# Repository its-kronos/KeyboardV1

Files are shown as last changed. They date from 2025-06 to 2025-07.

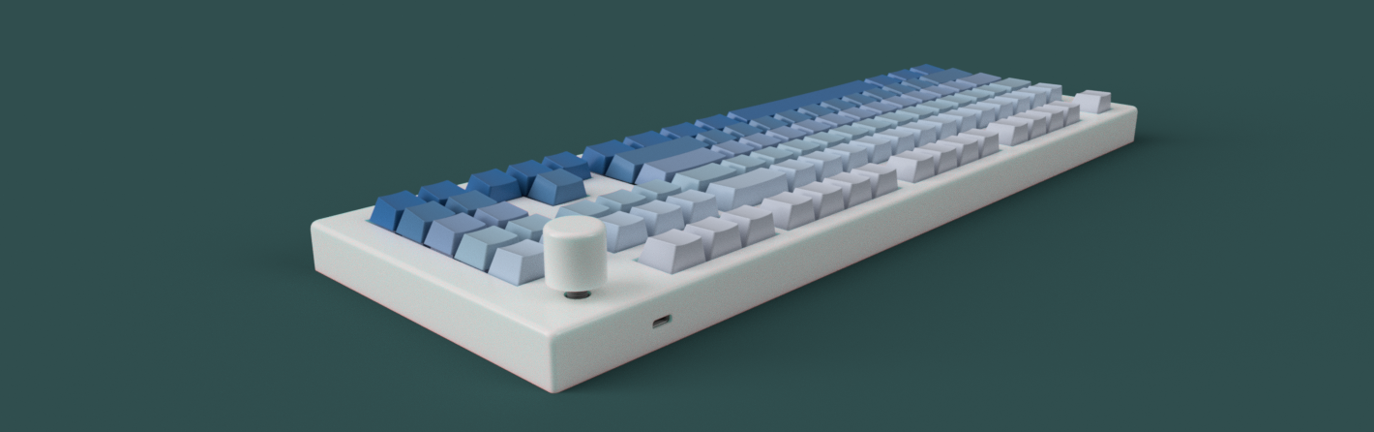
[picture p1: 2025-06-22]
Assets/Assembly.png

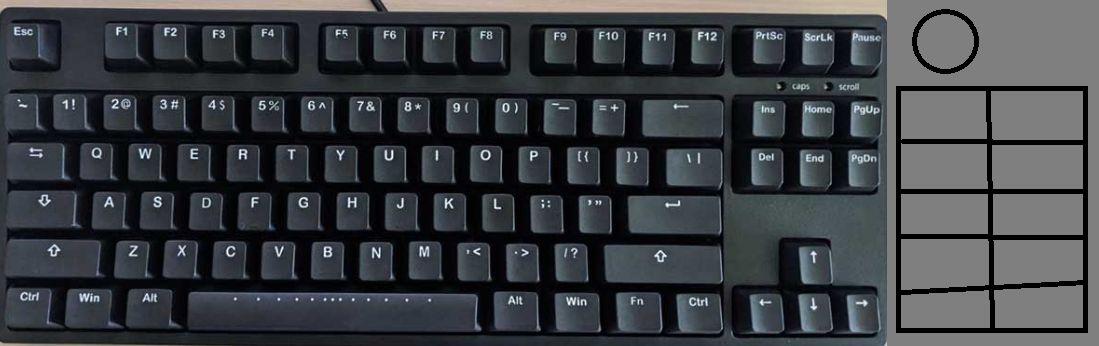
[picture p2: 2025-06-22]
Assets/LayoutPNG/Layout.png

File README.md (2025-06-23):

# MacroBoard

Assembly

# What is it?  
  
- The MacroBoard is an extension of a much smaller "macropad" featuring a **full TKL layout** with a **rotary encoder** for volume and a whopping total of **22 macro keys** (10 macrokeys physically and 12 more due to the fn keys being on another layer), and it is all coded with KMK firmware.
- Worried about the amount of power it will take? No need to worry! The MacroBoard has a **Pi Pico** as its brain, which is pretty efficient on energy.
- Dislike the microUSB connector on the Pi Pico? Again, don't worry! Through the use of a **USB Type-C** breakout board, most of the cables that you already use should work, as the keyboard has the necessary 5.1K ohm resistors to allow for type-C to type-C communication
- Case looking too big? Every model is split in half to allow for printing on a consumer-sized printer.

# Why did I make it?  
  
- One of my first hardware projects in my life was a macropad, and since I didn't have that much experience, I thought that a keyboard would be an appropriate step up in difficulty while still challenging myself, especially because I decided to use a **bare rp2040 chip** and had to include everything that it needs, including differential pair routing with 90 ohm impedence (for the USB-C connection).
- For the form-factor, I decided to add macrokeys as having additional components like a macroboard on my desk would feel like clutter, so incorporating these keys into the keyboard itself would fix this issue
- Finally, I just never used a mechanical keyboard before, and I honestly just wanted to know how it felt compared to the laptop keyboards and the ones based on rubber.



# Challenges  
  
- There were two points in this project that were quite soul-crushing and made me actually consider if I should just stop trying to complete the project, which is why I want to highlight them here.

- Initially, I decided that I would forgo hotswap switches for the keyboard, but after finishing routing the PCB, I chose that it would probably be better if I decided to include them. When I changed the footprints from Cherry MX to Kailh hotswap switches, there were over 1300 errors in the DRC.
- This meant that I would have to completely restart the wiring, which was pretty difficult for me to accept, but luckily, it took around 25% of the time it took before with my gained knowledge, proving to me how far I have come in this month alone.



- The next challenge happened right at the end of my project, or as I was almost ready to be done. When I uploaded the PCB gerber files to JLCPCB and completed the parts selection, I found out that no matter what I did, the bare board would come out to be over 1.5 KG, making it ineligible for Global Direct Shipping.
- This meant that the shipping for just the PCB would come out to be about 40 dollars with the cheapest option, completely breaking the $150 budget I had for this project.
- I asked around on the Hackclub Slack for some help, and I there seemed to be nothing that I could really do.
- As a last resort, I DMed [Ayo](https://github.com/TheEternalComrade) (you should check out his Github), who I had seen complete a keyboard. After discussing about ways to optimize the price, he brought up the idea of hand-wiring a keyboard, which was something I had never thought of before.
- I initially still felt discouraged, but with more conversation, I slowly became more confident in myself and my abilities. Now, rejuvinated, I updated the models to be able to work without a PCB and quickly finished my project



# Credits
- Credit to [@Coloneljesus_13723 on printables.com](https://www.printables.com/model/680438-switch-to-encoder-plate-adapter/files) for a cherry MX plate hole to EC11 rotary encoder
- [Ayo](https://github.com/TheEternalComrade) for helping me throughout the latter part of the project

# PCB

- As previously stated, I will be handwiring this keyboard, but here is my wiring diagram for the keyboard and the PCB that I did design (which ended up being too expensive)





# CAD
- This took me a pretty long time since I'm relatively new to designing things, but I feel that it turned out really well.



# BOM

|VENDER |ITEM |PRICE (USD) |SHIPPING|PCS |COUNT|COMMENT |COMMENT |
|---|---|---|---|---|-----|---|---|
| | | | | | | | |
|ALIEXPRESS| | | | | | | |
| |[FEET](https://www.aliexpress.us/item/3256807883232459.html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) |1.69 |0 |10 |1 | | |
| |[KEYCAPS](https://www.aliexpress.us/item/3256808583283524.html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) |20.22 |0 |104 |1 |BLUE | |
| |[STABS](https://www.aliexpress.us/item/3256806342416791.html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) |7.69 |0 |(1) 6.25u, (4) 2u|1 | | |
| |[ROTARY](https://www.aliexpress.us/item/3256806989461658.html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) |1.42 |0 |1 |0 |EXCLUDED | |
| |[HEADERS](https://www.aliexpress.us/item/3256804251926023.html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) |1.44 |1.99 |10 |0 |EXCLUDED | |
| |[STANDOFFS](https://www.aliexpress.us/item/3256807676471039.html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) |3.08 |0 |100 |1 |6mm M3 | |
| |[SCREWS](https://www.aliexpress.us/item/3256808318392916.html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) |2.12 |0 |50 |1 |14mm M3 | |
| |SCREWS (same as above) |1.81 |0 |50 |1 |8mm M3 | |
| |[WIRE](https://www.aliexpress.us/item/3256807263561521.html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) |5.04 |0 |10m |2 |22 AWG |PRICE IS FOR BOTH|
| |[SOLDER](https://www.aliexpress.us/item/2251832799951126.html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) |5.36 |0 |50G |1 |LEAD-FREE | |
| |[BRASS SPONGE](https://www.aliexpress.us/item/3256807379310777.html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,scm-url:1007.40050.354490.0,pvid:908ff35d-5b9a-412a-95bf-02d25e162938,tpp_buckets:668%232846%238107%231934&pdp_ext_f=%7B%22order%22%3A%2212272%22%2C%22eval%22%3A%221%22%2C%22sceneId%22%3A%2230050%22%7D&pdp_npi=4%40dis%21USD%211.23%211.02%21%21%211.23%211.02%21%40210308a417506046727721251ec22e%2112000041321995436%21rec%21US%21%21ABXZ&utparam-url=scene%3ApcDetailTopMoreOtherSeller%7Cquery_from%3A#nav-specification) |3.67 |0 |1 |1 |(so hackclub doesn't have to pay for tips in the future)| |
| |[DIODES](https://www.aliexpress.us/item/2255799955957794.html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) |1.46 |0 |100 |1 | | |
| | | | | | | | |
| |TOTAL |52.14 | | | | | |
| | | | | | | | |
|AMAZON | | | | | | | |
| |[GLUE](https://www.amazon.com/Gorilla-Precise-Cyanoacrylate-Dispensing-Anti-Clog/dp/B0CTHY7QTY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) |7.49 |0 |1 |1 | | |
| |[PICO](https://www.amazon.com/Raspberry-RP2040-microcontroller-Dual-core-Processor-1pc/dp/B0BK9CTMSV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) |7.48 |0 |2 |1 | | |
| |[USBC BREAKOUT](https://www.amazon.com/DIANN-Type-C-Breakout-Connector-Converter/dp/B0BLSN5PR8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)|5.99 |0 |5 |1 | | |
| |[WIRE STRIPPER](https://www.amazon.com/WGGE-Professional-crimping-Multi-Tool-Multi-Function/dp/B073YG65N2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)|8.99 |0 |1 |1 | | |
| |[SWITCHES](https://www.amazon.com/Switches-Mechanical-Keyboard-Pre-Lubed-Pin-Enhanced/dp/B0CF8CVWV8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) |32.99 |0 |108 |1 |gateron yellow | |
| | | | | | | | |
| |TOTAL |62.94 | | | | | |
| | | | | | | | |
|SHIPPING  |20 |(reserved for printing legion shipping) | | | | | |
|TAXES | |(Have more than enough for my state sales tax)| | | | | |
| | | | | | | | |
|TOTAL |135.08 | | | | | | |

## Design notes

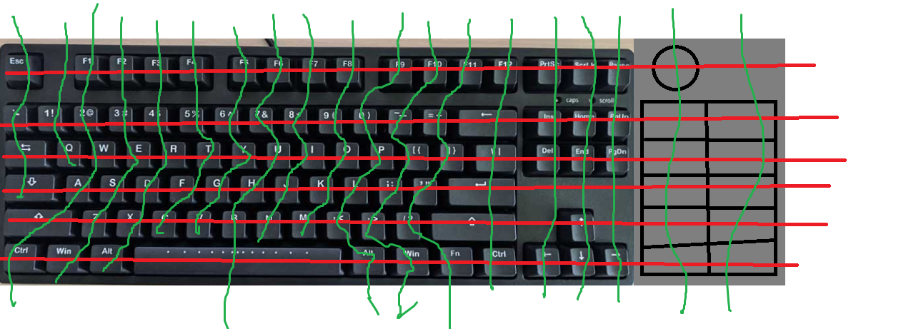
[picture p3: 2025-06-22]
Assets/LayoutPNG/Matrix.png

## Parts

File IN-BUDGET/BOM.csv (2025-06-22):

VENDER | ITEM | PRICE | SHIPPING | PCS | COUNT | COMMENT | COMMENT
ALIEXPRESS
 | FEET | 1.69 | 0 | 10 | 1
 | KEYCAPS | 20.22 | 0 | 104 | 1 | BLUE
 | STABS | 7.69 | 0 | (1) 6.25u, (4) 2u | 1
 | ROTARY | 1.42 | 0 | 1 | 0 | EXCLUDED
 | HEADERS | 1.44 | 1.99 | 10 | 0 | EXCLUDED
 | STANDOFFS | 3.08 | 0 | 100 | 1 | 6mm M3
 | SCREWS | 2.12 | 0 | 50 | 1 | 14mm M3
 | SCREWS | 1.81 | 0 | 50 | 1 | 8mm M3
 | WIRE | 5.04 | 0 | 10m | 2 | 22 AWG | PRICE IS FOR BOTH
 | SOLDER | 5.36 | 0 | 50G | 1 | LEAD-FREE
 | BRASS SPONGE | 3.67 | 0 | 1 | 1 | (so hackclub doesn’t have to pay for tips in the future)
 | DIODES | 1.46 | 0 | 100 | 1
 | TOTAL | 52.14
AMAZON
 | GLUE | 7.49 | 0 | 1 | 1
 | PICO | 7.48 | 0 | 2 | 1
 | USBC BREAKOUT | 5.99 | 0 | 5 | 1
 | WIRE STRIPPER | 8.99 | 0 | 1 | 1
 | SWITCHES | 32.99 | 0 | 108 | 1 | gateron yellow
 | TOTAL | 62.94
SHIPPING | 20 | (reserved for printing legion shipping)
TAXES |  | (Have more than enough for my state sales tax)
TOTAL | 135.08

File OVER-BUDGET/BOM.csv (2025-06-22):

JLC
 | PCB | 27.2
 | PCBA | 38.8 | (probably since I’m using RP2040 bare, meaning a lot of extended components)
 | PLATE | 6.83
 | shipping | 36.96
 | JLC TOTAL | 109.79
ALIEXPRESS
 | [switches](https://www.aliexpress.us/item/3256802556025161.html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) | 47.67 |  |  | cherry silver | 104 count
 | [keycaps]https://www.aliexpress.us/item/3256808583283524.html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 | 20.22 |  |  | gradient blue | 100% keyboard set
 | [STABS](https://www.aliexpress.us/item/3256806342416791.html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) | 7.69 |  |  |  | 4 2U 1 6.25U
 | [ENCODER](https://www.aliexpress.us/item/3256806989461658.html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 | 1.42 |  |  | ec11
 | [PIN_HEADERS](https://www.aliexpress.us/item/3256804251926023.html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) | 1.44 | 1.99 | (1.99 is shipping) | Uses 1x2 | 10 PCS
 | [STANDOFFS](https://www.aliexpress.us/item/3256807676471039.html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) | 3.94 |  |  | 6mm | 100 PCS
 | [SCREWS](https://www.aliexpress.us/item/3256808318392916.html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) | 1.58 |  |  | M3 6mm | 50 PCS
 | [SCREWS](https://www.aliexpress.us/item/3256808318392916.html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) | 2.03 |  |  | M3 12mm | 50 PCS
 | TOTAL | 87.98
AMAZON
 | [HOTSWAP](https://www.amazon.com/DUROCK-Mechanical-Keyboard-Switches-Hot-Swap/dp/B0B4W9YMGM | 13.99 |  |  |  | 110 PCS
 | [SUPERGLUE](https://www.amazon.com/Gorilla-Precise-Cyanoacrylate-Dispensing-Anti-Clog/dp/B0CTHY7QTY?s=office-products | 7.49
 | TOTAL | 21.48
SHIPPING (for Printing Legion)
 | SHIPPING | 20 | (at most, just an estimate)
 | TOTAL | 20
TOTAL PRICE | 239.25

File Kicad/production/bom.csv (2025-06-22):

Designator | Footprint | Quantity | Value | LCSC Part #
C1, C2 | 1206 | 2 | C10u
C10, C11 | 0402 | 2 | C15p
C12, C13, C14, C15, C16, C17, C4, C6, C7, C8, C9 | 0402 | 11 | C100n
C3, C5 | 0402 | 2 | C1u
D1 | D_SOD-323 | 1 | Esc
D10 | D_SOD-323 | 1 | F9
D11 | D_SOD-323 | 1 | F10
D12 | D_SOD-323 | 1 | F11
D13 | D_SOD-323 | 1 | F12
D14 | D_SOD-323 | 1 | PrtScrn
D15 | D_SOD-323 | 1 | Screen Lock
D16 | D_SOD-323 | 1 | Pause
D17 | D_SOD-323 | 1 | D
D18 | D_SOD-323 | 1 | KEY`
D19 | D_SOD-323 | 1 | KEY1
D2 | D_SOD-323 | 1 | F1
D20 | D_SOD-323 | 1 | KEY2
D21 | D_SOD-323 | 1 | KEY3
D22 | D_SOD-323 | 1 | KEY4
D23 | D_SOD-323 | 1 | KEY5
D24 | D_SOD-323 | 1 | KEY6
D25 | D_SOD-323 | 1 | KEY7
D26 | D_SOD-323 | 1 | KEY8
D27 | D_SOD-323 | 1 | KEY9
D28 | D_SOD-323 | 1 | KEY0
D29 | D_SOD-323 | 1 | KEY-
D3 | D_SOD-323 | 1 | F2
D30 | D_SOD-323 | 1 | KEY=
D31 | D_SOD-323 | 1 | BKSP
D32 | D_SOD-323 | 1 | Ins
D33 | D_SOD-323 | 1 | Home
D34 | D_SOD-323 | 1 | PgUP
D35 | D_SOD-323 | 1 | M1
D36 | D_SOD-323 | 1 | M2
D37 | D_SOD-323 | 1 | TAB
D38 | D_SOD-323 | 1 | KEYQ
D39 | D_SOD-323 | 1 | KEYW
D4 | D_SOD-323 | 1 | F3
D40 | D_SOD-323 | 1 | KEYE
D41 | D_SOD-323 | 1 | KEYR
D42 | D_SOD-323 | 1 | KEYT
D43 | D_SOD-323 | 1 | KEYY
D44 | D_SOD-323 | 1 | KEYU
D45 | D_SOD-323 | 1 | KEYI
D46 | D_SOD-323 | 1 | KEYO
D47 | D_SOD-323 | 1 | KEYP
D48 | D_SOD-323 | 1 | KEY[
D49 | D_SOD-323 | 1 | KEY]
D5 | D_SOD-323 | 1 | F4
D50 | D_SOD-323 | 1 | KEY\
D51 | D_SOD-323 | 1 | Del
D52 | D_SOD-323 | 1 | End
D53 | D_SOD-323 | 1 | PgDN
D54 | D_SOD-323 | 1 | M3
D55 | D_SOD-323 | 1 | M4
D56 | D_SOD-323 | 1 | CAPS
D57 | D_SOD-323 | 1 | KEYA
D58 | D_SOD-323 | 1 | KEYS
D59 | D_SOD-323 | 1 | KEYD
D6 | D_SOD-323 | 1 | F5
D60 | D_SOD-323 | 1 | KEYF
D61 | D_SOD-323 | 1 | KEYG
D62 | D_SOD-323 | 1 | KEYH
D63 | D_SOD-323 | 1 | KEYJ
D64 | D_SOD-323 | 1 | KEYK
D65 | D_SOD-323 | 1 | KEYL
D66 | D_SOD-323 | 1 | KEY;
D67 | D_SOD-323 | 1 | KEY"
D68 | D_SOD-323 | 1 | ENTER
D69 | D_SOD-323 | 1 | M5
D7 | D_SOD-323 | 1 | F6
D70 | D_SOD-323 | 1 | M6
D71 | D_SOD-323 | 1 | LSHIFT
D72 | D_SOD-323 | 1 | KEYZ
D73 | D_SOD-323 | 1 | KEYX
D74 | D_SOD-323 | 1 | KEYC
D75 | D_SOD-323 | 1 | KEYV
D76 | D_SOD-323 | 1 | KEYB
D77 | D_SOD-323 | 1 | KEYN
D78 | D_SOD-323 | 1 | KEYM
D79 | D_SOD-323 | 1 | KEY,
D8 | D_SOD-323 | 1 | F7
D80 | D_SOD-323 | 1 | KEY.
D81 | D_SOD-323 | 1 | KEY/
D82 | D_SOD-323 | 1 | RSHIFT
D83 | D_SOD-323 | 1 | Up Arrow
D84 | D_SOD-323 | 1 | M7
D85 | D_SOD-323 | 1 | M8
D86 | D_SOD-323 | 1 | LCTRL
D87 | D_SOD-323 | 1 | LWIN
D88 | D_SOD-323 | 1 | LALT
D89 | D_SOD-323 | 1 | SPACE
D9 | D_SOD-323 | 1 | F8
D90 | D_SOD-323 | 1 | RALT
D91 | D_SOD-323 | 1 | RWIN
D92 | D_SOD-323 | 1 | FN
D93 | D_SOD-323 | 1 | RCTRL
D94 | D_SOD-323 | 1 | Left Arrow
D95 | D_SOD-323 | 1 | Down Arrow
D96 | D_SOD-323 | 1 | Right Arrow
D97 | D_SOD-323 | 1 | M9
D98 | D_SOD-323 | 1 | M10
J2 | PinHeader_1x02_P2.54mm_Vertical | 1 | Conn_01x02
J3 | Korean Hroparts Elec - Type C 31 M 12 - 16P - USB 2.0 | 1 | USBC
R1, R2 | 0603 | 2 | R5.1k
R3, R5 | 0402 | 2 | R1K
R4, R8 | 0402 | 2 | R10K
R6, R7 | 0402 | 2 | R27.4
SW1 | RotaryEncoder_Alps_EC11E-Switch_Vertical_H20mm_MountingHoles | 1 | RotaryEncoder_Switch
SW10 | SW_Hotswap_Kailh_MX_Plated_1.00u | 1 | F8
SW11 | SW_Hotswap_Kailh_MX_Plated_1.00u | 1 | F9
SW12 | SW_Hotswap_Kailh_MX_Plated_1.00u | 1 | F10
SW13 | SW_Hotswap_Kailh_MX_Plated_1.00u | 1 | F11
SW14 | SW_Hotswap_Kailh_MX_Plated_1.00u | 1 | F12
SW15 | SW_Hotswap_Kailh_MX_Plated_1.00u | 1 | PrtScrn
SW16 | SW_Hotswap_Kailh_MX_Plated_1.00u | 1 | Screen Lock
SW17 | SW_Hotswap_Kailh_MX_Plated_1.00u | 1 | Pause
SW18 | SW_Hotswap_Kailh_MX_Plated_1.00u | 1 | KEY`
SW19 | SW_Hotswap_Kailh_MX_Plated_1.00u | 1 | KEY1
SW2 | SW_Hotswap_Kailh_MX_Plated_1.00u | 1 | Esc
SW20 | SW_Hotswap_Kailh_MX_Plated_1.00u | 1 | KEY2
SW21 | SW_Hotswap_Kailh_MX_Plated_1.00u | 1 | KEY3
SW22 | SW_Hotswap_Kailh_MX_Plated_1.00u | 1 | KEY4
SW23 | SW_Hotswap_Kailh_MX_Plated_1.00u | 1 | KEY5
SW24 | SW_Hotswap_Kailh_MX_Plated_1.00u | 1 | KEY6
SW25 | SW_Hotswap_Kailh_MX_Plated_1.00u | 1 | KEY7
SW26 | SW_Hotswap_Kailh_MX_Plated_1.00u | 1 | KEY8
SW27 | SW_Hotswap_Kailh_MX_Plated_1.00u | 1 | KEY9
SW28 | SW_Hotswap_Kailh_MX_Plated_1.00u | 1 | KEY0
SW29 | SW_Hotswap_Kailh_MX_Plated_1.00u | 1 | KEY-
SW3 | SW_Hotswap_Kailh_MX_Plated_1.00u | 1 | F1
SW30 | SW_Hotswap_Kailh_MX_Plated_1.00u | 1 | KEY=
SW31 | SW_Hotswap_Kailh_MX_Plated_2.00u | 1 | BKSP
SW32 | SW_Hotswap_Kailh_MX_Plated_1.00u | 1 | Ins
SW33 | SW_Hotswap_Kailh_MX_Plated_1.00u | 1 | Home
SW34 | SW_Hotswap_Kailh_MX_Plated_1.00u | 1 | PgUP
SW35 | SW_Hotswap_Kailh_MX_Plated_1.00u | 1 | M1
SW36 | SW_Hotswap_Kailh_MX_Plated_1.00u | 1 | M2
SW37 | SW_Hotswap_Kailh_MX_Plated_1.50u | 1 | TAB
SW38 | SW_Hotswap_Kailh_MX_Plated_1.00u | 1 | KEYQ
SW39 | SW_Hotswap_Kailh_MX_Plated_1.00u | 1 | KEYW
SW4 | SW_Hotswap_Kailh_MX_Plated_1.00u | 1 | F2
SW40 | SW_Hotswap_Kailh_MX_Plated_1.00u | 1 | KEYE
SW41 | SW_Hotswap_Kailh_MX_Plated_1.00u | 1 | KEYR
SW42 | SW_Hotswap_Kailh_MX_Plated_1.00u | 1 | KEYT
SW43 | SW_Hotswap_Kailh_MX_Plated_1.00u | 1 | KEYY
SW44 | SW_Hotswap_Kailh_MX_Plated_1.00u | 1 | KEYU
SW45 | SW_Hotswap_Kailh_MX_Plated_1.00u | 1 | KEYI
SW46 | SW_Hotswap_Kailh_MX_Plated_1.00u | 1 | KEYO
SW47 | SW_Hotswap_Kailh_MX_Plated_1.00u | 1 | KEYP
SW48 | SW_Hotswap_Kailh_MX_Plated_1.00u | 1 | KEY[
SW49 | SW_Hotswap_Kailh_MX_Plated_1.00u | 1 | KEY]
SW5 | SW_Hotswap_Kailh_MX_Plated_1.00u | 1 | F3
SW50 | SW_Hotswap_Kailh_MX_Plated_1.50u | 1 | KEY\
SW51 | SW_Hotswap_Kailh_MX_Plated_1.00u | 1 | Del
SW52 | SW_Hotswap_Kailh_MX_Plated_1.00u | 1 | End
SW53 | SW_Hotswap_Kailh_MX_Plated_1.00u | 1 | PgDN
SW54 | SW_Hotswap_Kailh_MX_Plated_1.00u | 1 | M3
SW55 | SW_Hotswap_Kailh_MX_Plated_1.00u | 1 | M4
SW56 | SW_Hotswap_Kailh_MX_Plated_1.75u | 1 | CAPS
SW57 | SW_Hotswap_Kailh_MX_Plated_1.00u | 1 | KEYA
SW58 | SW_Hotswap_Kailh_MX_Plated_1.00u | 1 | KEYS
SW59 | SW_Hotswap_Kailh_MX_Plated_1.00u | 1 | KEYD
SW6 | SW_Hotswap_Kailh_MX_Plated_1.00u | 1 | F4
SW60 | SW_Hotswap_Kailh_MX_Plated_1.00u | 1 | KEYF
SW61 | SW_Hotswap_Kailh_MX_Plated_1.00u | 1 | KEYG
SW62 | SW_Hotswap_Kailh_MX_Plated_1.00u | 1 | KEYH
SW63 | SW_Hotswap_Kailh_MX_Plated_1.00u | 1 | KEYJ
SW64 | SW_Hotswap_Kailh_MX_Plated_1.00u | 1 | KEYK
SW65 | SW_Hotswap_Kailh_MX_Plated_1.00u | 1 | KEYL
SW66 | SW_Hotswap_Kailh_MX_Plated_1.00u | 1 | KEY;
SW67 | SW_Hotswap_Kailh_MX_Plated_1.00u | 1 | KEY"
SW68 | SW_Hotswap_Kailh_MX_Plated_2.25u | 1 | ENTER
SW69 | SW_Hotswap_Kailh_MX_Plated_1.00u | 1 | M5
SW7 | SW_Hotswap_Kailh_MX_Plated_1.00u | 1 | F5
SW70 | SW_Hotswap_Kailh_MX_Plated_1.00u | 1 | M6
SW71 | SW_Hotswap_Kailh_MX_Plated_2.25u | 1 | LSHIFT
SW72 | SW_Hotswap_Kailh_MX_Plated_1.00u | 1 | KEYZ
SW73 | SW_Hotswap_Kailh_MX_Plated_1.00u | 1 | KEYX
SW74 | SW_Hotswap_Kailh_MX_Plated_1.00u | 1 | KEYC
SW75 | SW_Hotswap_Kailh_MX_Plated_1.00u | 1 | KEYV
SW76 | SW_Hotswap_Kailh_MX_Plated_1.00u | 1 | KEYB
SW77 | SW_Hotswap_Kailh_MX_Plated_1.00u | 1 | KEYN
SW78 | SW_Hotswap_Kailh_MX_Plated_1.00u | 1 | KEYM
SW79 | SW_Hotswap_Kailh_MX_Plated_1.00u | 1 | KEY,
SW8 | SW_Hotswap_Kailh_MX_Plated_1.00u | 1 | F6
SW80 | SW_Hotswap_Kailh_MX_Plated_1.00u | 1 | KEY.
SW81 | SW_Hotswap_Kailh_MX_Plated_1.00u | 1 | KEY/
SW82 | SW_Hotswap_Kailh_MX_Plated_2.75u | 1 | RSHIFT
SW83 | SW_Hotswap_Kailh_MX_Plated_1.00u | 1 | Up Arrow
SW84 | SW_Hotswap_Kailh_MX_Plated_1.00u | 1 | M7
SW85 | SW_Hotswap_Kailh_MX_Plated_1.00u | 1 | M8
SW86 | SW_Hotswap_Kailh_MX_Plated_1.25u | 1 | LCTRL
SW87 | SW_Hotswap_Kailh_MX_Plated_1.25u | 1 | LWIN
SW88 | SW_Hotswap_Kailh_MX_Plated_1.25u | 1 | LALT
SW89 | SW_Hotswap_Kailh_MX_Plated_6.25u | 1 | SPACE
SW9 | SW_Hotswap_Kailh_MX_Plated_1.00u | 1 | F7
SW90 | SW_Hotswap_Kailh_MX_Plated_1.25u | 1 | RALT
SW91 | SW_Hotswap_Kailh_MX_Plated_1.25u | 1 | RWIN
SW92 | SW_Hotswap_Kailh_MX_Plated_1.25u | 1 | FN
SW93 | SW_Hotswap_Kailh_MX_Plated_1.25u | 1 | RCTRL
SW94 | SW_Hotswap_Kailh_MX_Plated_1.00u | 1 | Left Arrow
SW95 | SW_Hotswap_Kailh_MX_Plated_1.00u | 1 | Down Arrow
SW96 | SW_Hotswap_Kailh_MX_Plated_1.00u | 1 | Right Arrow
SW97 | SW_Hotswap_Kailh_MX_Plated_1.00u | 1 | M9
SW98 | SW_Hotswap_Kailh_MX_Plated_1.00u | 1 | M10
U1 | QFN-56-1EP_7x7mm_P0.4mm_EP3.2x3.2mm | 1 | RP2040
U2 | SOT-223-3_TabPin2 | 1 | NCP1117-3.3_SOT223
U3 | SOIC-8_5.3x5.3mm_P1.27mm | 1 | W25Q128JVS
U4 | SOIC-8_3.9x4.9mm_P1.27mm | 1 | USB6B1
Y1 | Crystal_SMD_3225-4Pin_3.2x2.5mm | 1 | Crystal_GND24

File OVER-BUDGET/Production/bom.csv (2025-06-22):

Designator | Footprint | Quantity | Value | LCSC Part #
C1, C2 | 1206 | 2 | C10u | C13585
C10, C11 | 402 | 2 | C15p | C1548
C12, C13, C14, C15, C16, C17, C4, C6, C7, C8, C9 | 402 | 11 | C100n | C1525
C3, C5 | 402 | 2 | C1u | C52923
D1 | D_SOD-323 | 1 | Esc | C2128
D10 | D_SOD-323 | 1 | F9 | C2128
D11 | D_SOD-323 | 1 | F10 | C2128
D12 | D_SOD-323 | 1 | F11 | C2128
D13 | D_SOD-323 | 1 | F12 | C2128
D14 | D_SOD-323 | 1 | PrtScrn | C2128
D15 | D_SOD-323 | 1 | Screen Lock | C2128
D16 | D_SOD-323 | 1 | Pause | C2128
D17 | D_SOD-323 | 1 | D | C2128
D18 | D_SOD-323 | 1 | KEY` | C2128
D19 | D_SOD-323 | 1 | KEY1 | C2128
D2 | D_SOD-323 | 1 | F1 | C2128
D20 | D_SOD-323 | 1 | KEY2 | C2128
D21 | D_SOD-323 | 1 | KEY3 | C2128
D22 | D_SOD-323 | 1 | KEY4 | C2128
D23 | D_SOD-323 | 1 | KEY5 | C2128
D24 | D_SOD-323 | 1 | KEY6 | C2128
D25 | D_SOD-323 | 1 | KEY7 | C2128
D26 | D_SOD-323 | 1 | KEY8 | C2128
D27 | D_SOD-323 | 1 | KEY9 | C2128
D28 | D_SOD-323 | 1 | KEY0 | C2128
D29 | D_SOD-323 | 1 | KEY- | C2128
D3 | D_SOD-323 | 1 | F2 | C2128
D30 | D_SOD-323 | 1 | KEY= | C2128
D31 | D_SOD-323 | 1 | BKSP | C2128
D32 | D_SOD-323 | 1 | Ins | C2128
D33 | D_SOD-323 | 1 | Home | C2128
D34 | D_SOD-323 | 1 | PgUP | C2128
D35 | D_SOD-323 | 1 | M1 | C2128
D36 | D_SOD-323 | 1 | M2 | C2128
D37 | D_SOD-323 | 1 | TAB | C2128
D38 | D_SOD-323 | 1 | KEYQ | C2128
D39 | D_SOD-323 | 1 | KEYW | C2128
D4 | D_SOD-323 | 1 | F3 | C2128
D40 | D_SOD-323 | 1 | KEYE | C2128
D41 | D_SOD-323 | 1 | KEYR | C2128
D42 | D_SOD-323 | 1 | KEYT | C2128
D43 | D_SOD-323 | 1 | KEYY | C2128
D44 | D_SOD-323 | 1 | KEYU | C2128
D45 | D_SOD-323 | 1 | KEYI | C2128
D46 | D_SOD-323 | 1 | KEYO | C2128
D47 | D_SOD-323 | 1 | KEYP | C2128
D48 | D_SOD-323 | 1 | KEY[ | C2128
D49 | D_SOD-323 | 1 | KEY] | C2128
D5 | D_SOD-323 | 1 | F4 | C2128
D50 | D_SOD-323 | 1 | KEY\ | C2128
D51 | D_SOD-323 | 1 | Del | C2128
D52 | D_SOD-323 | 1 | End | C2128
D53 | D_SOD-323 | 1 | PgDN | C2128
D54 | D_SOD-323 | 1 | M3 | C2128
D55 | D_SOD-323 | 1 | M4 | C2128
D56 | D_SOD-323 | 1 | CAPS | C2128
D57 | D_SOD-323 | 1 | KEYA | C2128
D58 | D_SOD-323 | 1 | KEYS | C2128
D59 | D_SOD-323 | 1 | KEYD | C2128
D6 | D_SOD-323 | 1 | F5 | C2128
D60 | D_SOD-323 | 1 | KEYF | C2128
D61 | D_SOD-323 | 1 | KEYG | C2128
D62 | D_SOD-323 | 1 | KEYH | C2128
D63 | D_SOD-323 | 1 | KEYJ | C2128
D64 | D_SOD-323 | 1 | KEYK | C2128
D65 | D_SOD-323 | 1 | KEYL | C2128
D66 | D_SOD-323 | 1 | KEY; | C2128
D67 | D_SOD-323 | 1 | KEY" | C2128
D68 | D_SOD-323 | 1 | ENTER | C2128
D69 | D_SOD-323 | 1 | M5 | C2128
D7 | D_SOD-323 | 1 | F6 | C2128
D70 | D_SOD-323 | 1 | M6 | C2128
D71 | D_SOD-323 | 1 | LSHIFT | C2128
D72 | D_SOD-323 | 1 | KEYZ | C2128
D73 | D_SOD-323 | 1 | KEYX | C2128
D74 | D_SOD-323 | 1 | KEYC | C2128
D75 | D_SOD-323 | 1 | KEYV | C2128
D76 | D_SOD-323 | 1 | KEYB | C2128
D77 | D_SOD-323 | 1 | KEYN | C2128
D78 | D_SOD-323 | 1 | KEYM | C2128
D79 | D_SOD-323 | 1 | KEY, | C2128
D8 | D_SOD-323 | 1 | F7 | C2128
D80 | D_SOD-323 | 1 | KEY. | C2128
D81 | D_SOD-323 | 1 | KEY/ | C2128
D82 | D_SOD-323 | 1 | RSHIFT | C2128
D83 | D_SOD-323 | 1 | Up Arrow | C2128
D84 | D_SOD-323 | 1 | M7 | C2128
D85 | D_SOD-323 | 1 | M8 | C2128
D86 | D_SOD-323 | 1 | LCTRL | C2128
D87 | D_SOD-323 | 1 | LWIN | C2128
D88 | D_SOD-323 | 1 | LALT | C2128
D89 | D_SOD-323 | 1 | SPACE | C2128
D9 | D_SOD-323 | 1 | F8 | C2128
D90 | D_SOD-323 | 1 | RALT | C2128
D91 | D_SOD-323 | 1 | RWIN | C2128
D92 | D_SOD-323 | 1 | FN | C2128
D93 | D_SOD-323 | 1 | RCTRL | C2128
D94 | D_SOD-323 | 1 | Left Arrow | C2128
D95 | D_SOD-323 | 1 | Down Arrow | C2128
D96 | D_SOD-323 | 1 | Right Arrow | C2128
D97 | D_SOD-323 | 1 | M9 | C2128
D98 | D_SOD-323 | 1 | M10 | C2128
J2 | PinHeader_1x02_P2.54mm_Vertical | 1 | Conn_01x02 | DNF
J3 | Korean Hroparts Elec - Type C 31 M 12 - 16P - USB 2.0 | 1 | USBC | C165948
R1, R2 | 603 | 2 | R5.1k | C23186
R3, R5 | 402 | 2 | R1K | C11702
R4, R8 | 402 | 2 | R10K | C25744
R6, R7 | 402 | 2 | R27.4 | C31439
SW1 | RotaryEncoder_Alps_EC11E-Switch_Vertical_H20mm_MountingHoles | 1 | RotaryEncoder_Switch | DNF
SW10 | SW_Hotswap_Kailh_MX_Plated_1.00u | 1 | F8 | DNF
SW11 | SW_Hotswap_Kailh_MX_Plated_1.00u | 1 | F9 | DNF
SW12 | SW_Hotswap_Kailh_MX_Plated_1.00u | 1 | F10 | DNF
SW13 | SW_Hotswap_Kailh_MX_Plated_1.00u | 1 | F11 | DNF
SW14 | SW_Hotswap_Kailh_MX_Plated_1.00u | 1 | F12 | DNF
SW15 | SW_Hotswap_Kailh_MX_Plated_1.00u | 1 | PrtScrn | DNF
SW16 | SW_Hotswap_Kailh_MX_Plated_1.00u | 1 | Screen Lock | DNF
SW17 | SW_Hotswap_Kailh_MX_Plated_1.00u | 1 | Pause | DNF
SW18 | SW_Hotswap_Kailh_MX_Plated_1.00u | 1 | KEY` | DNF
SW19 | SW_Hotswap_Kailh_MX_Plated_1.00u | 1 | KEY1 | DNF
SW2 | SW_Hotswap_Kailh_MX_Plated_1.00u | 1 | Esc | DNF
SW20 | SW_Hotswap_Kailh_MX_Plated_1.00u | 1 | KEY2 | DNF
SW21 | SW_Hotswap_Kailh_MX_Plated_1.00u | 1 | KEY3 | DNF
SW22 | SW_Hotswap_Kailh_MX_Plated_1.00u | 1 | KEY4 | DNF
SW23 | SW_Hotswap_Kailh_MX_Plated_1.00u | 1 | KEY5 | DNF
SW24 | SW_Hotswap_Kailh_MX_Plated_1.00u | 1 | KEY6 | DNF
SW25 | SW_Hotswap_Kailh_MX_Plated_1.00u | 1 | KEY7 | DNF
SW26 | SW_Hotswap_Kailh_MX_Plated_1.00u | 1 | KEY8 | DNF
SW27 | SW_Hotswap_Kailh_MX_Plated_1.00u | 1 | KEY9 | DNF
SW28 | SW_Hotswap_Kailh_MX_Plated_1.00u | 1 | KEY0 | DNF
SW29 | SW_Hotswap_Kailh_MX_Plated_1.00u | 1 | KEY- | DNF
SW3 | SW_Hotswap_Kailh_MX_Plated_1.00u | 1 | F1 | DNF
SW30 | SW_Hotswap_Kailh_MX_Plated_1.00u | 1 | KEY= | DNF
SW31 | SW_Hotswap_Kailh_MX_Plated_2.00u | 1 | BKSP | DNF
SW32 | SW_Hotswap_Kailh_MX_Plated_1.00u | 1 | Ins | DNF
SW33 | SW_Hotswap_Kailh_MX_Plated_1.00u | 1 | Home | DNF
SW34 | SW_Hotswap_Kailh_MX_Plated_1.00u | 1 | PgUP | DNF
SW35 | SW_Hotswap_Kailh_MX_Plated_1.00u | 1 | M1 | DNF
SW36 | SW_Hotswap_Kailh_MX_Plated_1.00u | 1 | M2 | DNF
SW37 | SW_Hotswap_Kailh_MX_Plated_1.50u | 1 | TAB | DNF
SW38 | SW_Hotswap_Kailh_MX_Plated_1.00u | 1 | KEYQ | DNF
SW39 | SW_Hotswap_Kailh_MX_Plated_1.00u | 1 | KEYW | DNF
SW4 | SW_Hotswap_Kailh_MX_Plated_1.00u | 1 | F2 | DNF
SW40 | SW_Hotswap_Kailh_MX_Plated_1.00u | 1 | KEYE | DNF
SW41 | SW_Hotswap_Kailh_MX_Plated_1.00u | 1 | KEYR | DNF
SW42 | SW_Hotswap_Kailh_MX_Plated_1.00u | 1 | KEYT | DNF
SW43 | SW_Hotswap_Kailh_MX_Plated_1.00u | 1 | KEYY | DNF
SW44 | SW_Hotswap_Kailh_MX_Plated_1.00u | 1 | KEYU | DNF
SW45 | SW_Hotswap_Kailh_MX_Plated_1.00u | 1 | KEYI | DNF
SW46 | SW_Hotswap_Kailh_MX_Plated_1.00u | 1 | KEYO | DNF
SW47 | SW_Hotswap_Kailh_MX_Plated_1.00u | 1 | KEYP | DNF
SW48 | SW_Hotswap_Kailh_MX_Plated_1.00u | 1 | KEY[ | DNF
SW49 | SW_Hotswap_Kailh_MX_Plated_1.00u | 1 | KEY] | DNF
SW5 | SW_Hotswap_Kailh_MX_Plated_1.00u | 1 | F3 | DNF
SW50 | SW_Hotswap_Kailh_MX_Plated_1.50u | 1 | KEY\ | DNF
SW51 | SW_Hotswap_Kailh_MX_Plated_1.00u | 1 | Del | DNF
SW52 | SW_Hotswap_Kailh_MX_Plated_1.00u | 1 | End | DNF
SW53 | SW_Hotswap_Kailh_MX_Plated_1.00u | 1 | PgDN | DNF
SW54 | SW_Hotswap_Kailh_MX_Plated_1.00u | 1 | M3 | DNF
SW55 | SW_Hotswap_Kailh_MX_Plated_1.00u | 1 | M4 | DNF
SW56 | SW_Hotswap_Kailh_MX_Plated_1.75u | 1 | CAPS | DNF
SW57 | SW_Hotswap_Kailh_MX_Plated_1.00u | 1 | KEYA | DNF
SW58 | SW_Hotswap_Kailh_MX_Plated_1.00u | 1 | KEYS | DNF
SW59 | SW_Hotswap_Kailh_MX_Plated_1.00u | 1 | KEYD | DNF
SW6 | SW_Hotswap_Kailh_MX_Plated_1.00u | 1 | F4 | DNF
SW60 | SW_Hotswap_Kailh_MX_Plated_1.00u | 1 | KEYF | DNF
SW61 | SW_Hotswap_Kailh_MX_Plated_1.00u | 1 | KEYG | DNF
SW62 | SW_Hotswap_Kailh_MX_Plated_1.00u | 1 | KEYH | DNF
SW63 | SW_Hotswap_Kailh_MX_Plated_1.00u | 1 | KEYJ | DNF
SW64 | SW_Hotswap_Kailh_MX_Plated_1.00u | 1 | KEYK | DNF
SW65 | SW_Hotswap_Kailh_MX_Plated_1.00u | 1 | KEYL | DNF
SW66 | SW_Hotswap_Kailh_MX_Plated_1.00u | 1 | KEY; | DNF
SW67 | SW_Hotswap_Kailh_MX_Plated_1.00u | 1 | KEY" | DNF
SW68 | SW_Hotswap_Kailh_MX_Plated_2.25u | 1 | ENTER | DNF
SW69 | SW_Hotswap_Kailh_MX_Plated_1.00u | 1 | M5 | DNF
SW7 | SW_Hotswap_Kailh_MX_Plated_1.00u | 1 | F5 | DNF
SW70 | SW_Hotswap_Kailh_MX_Plated_1.00u | 1 | M6 | DNF
SW71 | SW_Hotswap_Kailh_MX_Plated_2.25u | 1 | LSHIFT | DNF
SW72 | SW_Hotswap_Kailh_MX_Plated_1.00u | 1 | KEYZ | DNF
SW73 | SW_Hotswap_Kailh_MX_Plated_1.00u | 1 | KEYX | DNF
SW74 | SW_Hotswap_Kailh_MX_Plated_1.00u | 1 | KEYC | DNF
SW75 | SW_Hotswap_Kailh_MX_Plated_1.00u | 1 | KEYV | DNF
SW76 | SW_Hotswap_Kailh_MX_Plated_1.00u | 1 | KEYB | DNF
SW77 | SW_Hotswap_Kailh_MX_Plated_1.00u | 1 | KEYN | DNF
SW78 | SW_Hotswap_Kailh_MX_Plated_1.00u | 1 | KEYM | DNF
SW79 | SW_Hotswap_Kailh_MX_Plated_1.00u | 1 | KEY, | DNF
SW8 | SW_Hotswap_Kailh_MX_Plated_1.00u | 1 | F6 | DNF
SW80 | SW_Hotswap_Kailh_MX_Plated_1.00u | 1 | KEY. | DNF
SW81 | SW_Hotswap_Kailh_MX_Plated_1.00u | 1 | KEY/ | DNF
SW82 | SW_Hotswap_Kailh_MX_Plated_2.75u | 1 | RSHIFT | DNF
SW83 | SW_Hotswap_Kailh_MX_Plated_1.00u | 1 | Up Arrow | DNF
SW84 | SW_Hotswap_Kailh_MX_Plated_1.00u | 1 | M7 | DNF
SW85 | SW_Hotswap_Kailh_MX_Plated_1.00u | 1 | M8 | DNF
SW86 | SW_Hotswap_Kailh_MX_Plated_1.25u | 1 | LCTRL | DNF
SW87 | SW_Hotswap_Kailh_MX_Plated_1.25u | 1 | LWIN | DNF
SW88 | SW_Hotswap_Kailh_MX_Plated_1.25u | 1 | LALT | DNF
SW89 | SW_Hotswap_Kailh_MX_Plated_6.25u | 1 | SPACE | DNF
SW9 | SW_Hotswap_Kailh_MX_Plated_1.00u | 1 | F7 | DNF
SW90 | SW_Hotswap_Kailh_MX_Plated_1.25u | 1 | RALT | DNF
SW91 | SW_Hotswap_Kailh_MX_Plated_1.25u | 1 | RWIN | DNF
SW92 | SW_Hotswap_Kailh_MX_Plated_1.25u | 1 | FN | DNF
SW93 | SW_Hotswap_Kailh_MX_Plated_1.25u | 1 | RCTRL | DNF
SW94 | SW_Hotswap_Kailh_MX_Plated_1.00u | 1 | Left Arrow | DNF
SW95 | SW_Hotswap_Kailh_MX_Plated_1.00u | 1 | Down Arrow | DNF
SW96 | SW_Hotswap_Kailh_MX_Plated_1.00u | 1 | Right Arrow | DNF
SW97 | SW_Hotswap_Kailh_MX_Plated_1.00u | 1 | M9 | DNF
SW98 | SW_Hotswap_Kailh_MX_Plated_1.00u | 1 | M10 | DNF
U1 | QFN-56-1EP_7x7mm_P0.4mm_EP3.2x3.2mm | 1 | RP2040 | C2040
U2 | SOT-223-3_TabPin2 | 1 | NCP1117-3.3_SOT223 | C26537
U3 | SOIC-8_5.3x5.3mm_P1.27mm | 1 | W25Q128JVS | C97521
U4 | SOIC-8_3.9x4.9mm_P1.27mm | 1 | USB6B1 | C7419953
Y1 | Crystal_SMD_3225-4Pin_3.2x2.5mm | 1 | Crystal_GND24 | C20625731

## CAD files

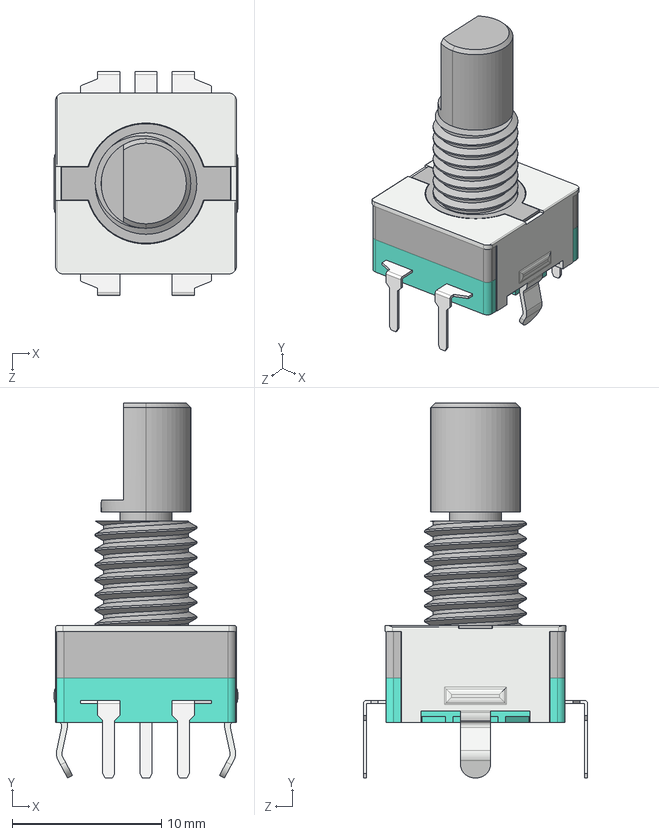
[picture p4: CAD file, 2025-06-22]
Assets/Models/Rotary_Encoder/EC11_Vertical.STEP
12.3 x 25.1 x 15.0 mm

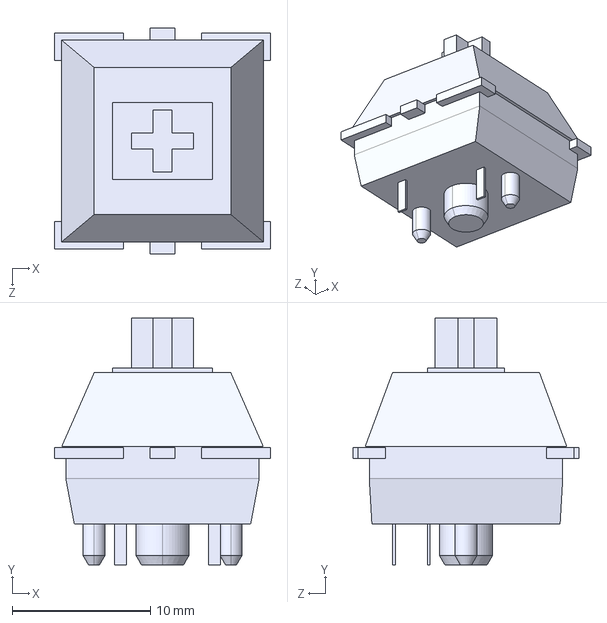
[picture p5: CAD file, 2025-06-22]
Assets/Models/Switches/Cherry_MX_Switch.STEP
15.6 x 17.9 x 16.3 mm

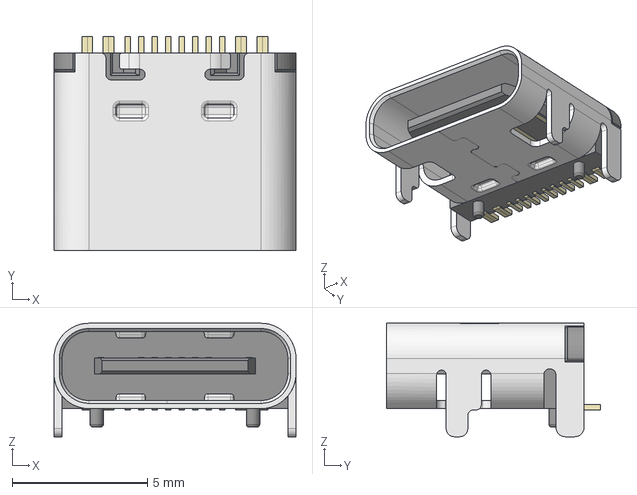
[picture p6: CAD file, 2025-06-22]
Assets/Models/USB/Type-C/Korean_Hroparts-16P-Female.step
8.95 x 7.90 x 4.20 mm

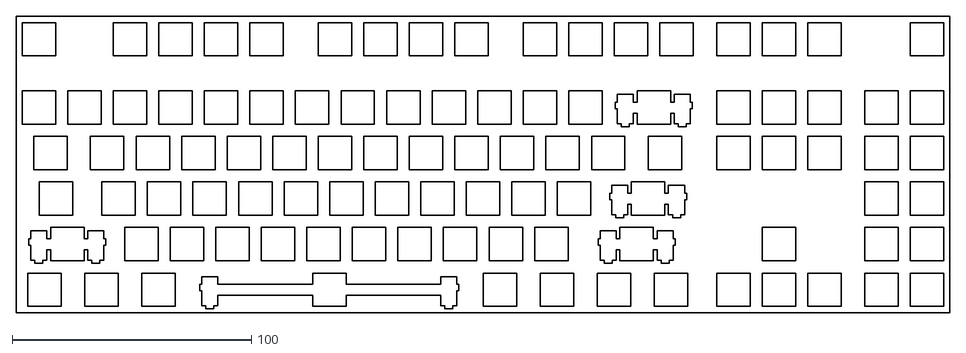
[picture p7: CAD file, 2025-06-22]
Assets/plate.dxf
390.5 x 123.8

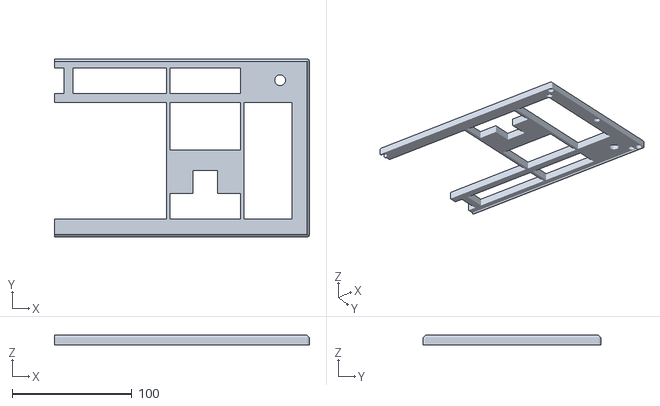
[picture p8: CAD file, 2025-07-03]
IN-BUDGET/Production/CAD/CaseTopRight.stl
212.6 x 148.4 x 8.00

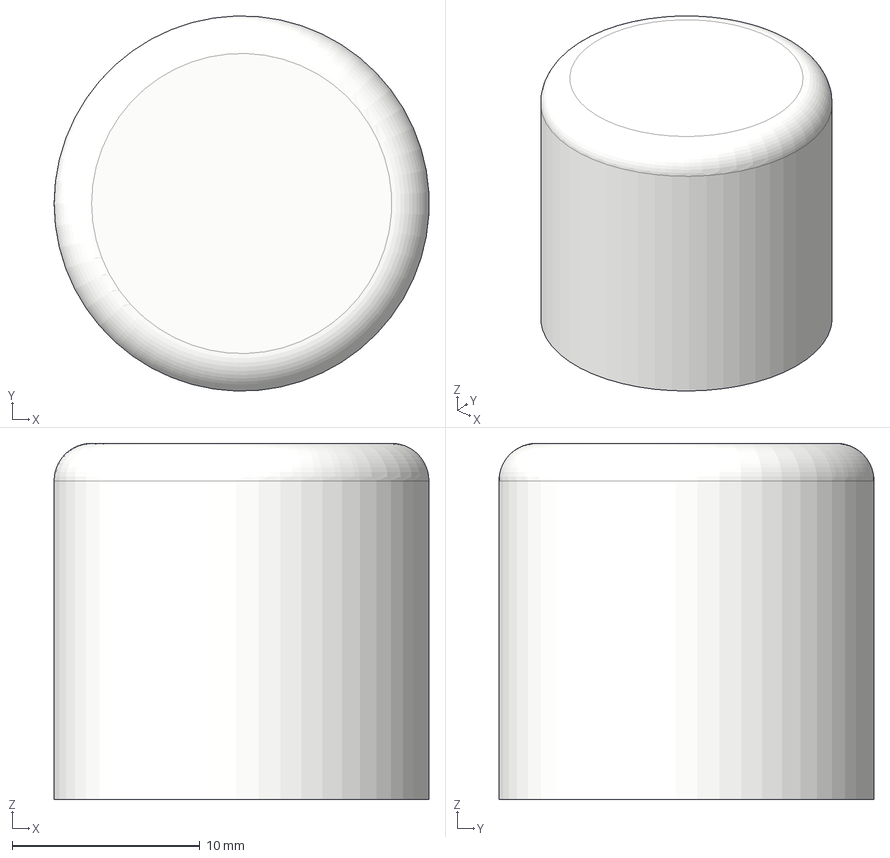
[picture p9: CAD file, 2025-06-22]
Models/rotEncoderCap.step
20.0 x 20.0 x 19.0 mm

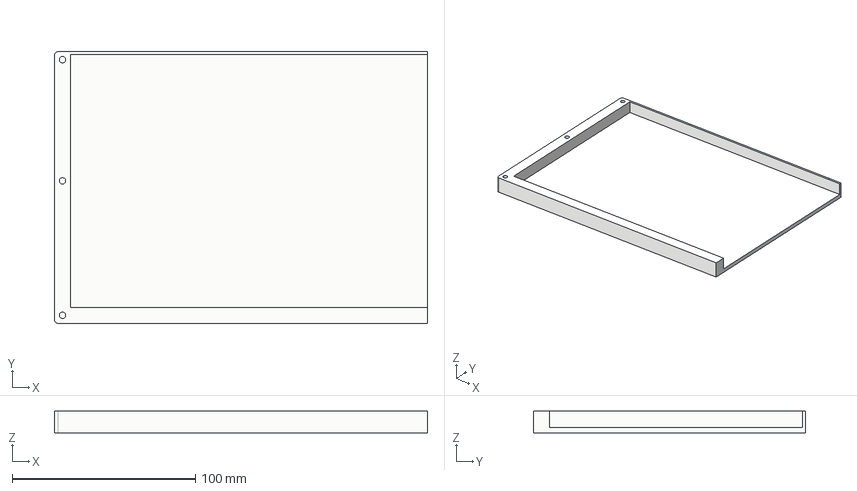
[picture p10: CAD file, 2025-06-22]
OVER-BUDGET/Production/CaseBottomLeft.step
203.7 x 148.4 x 12.0 mm

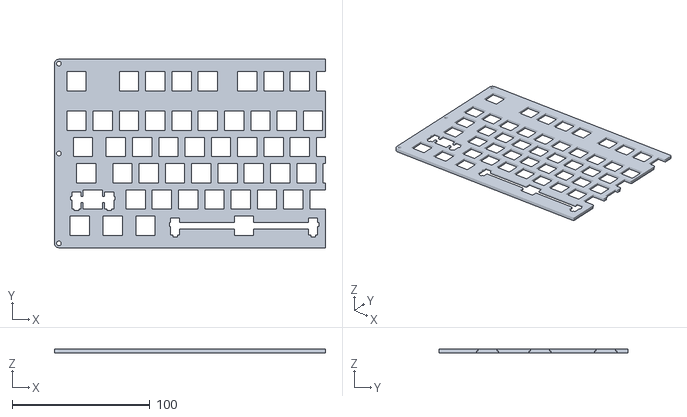
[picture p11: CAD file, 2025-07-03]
IN-BUDGET/Production/CAD/plateLeft.stl
196.4 x 136.6 x 3.00

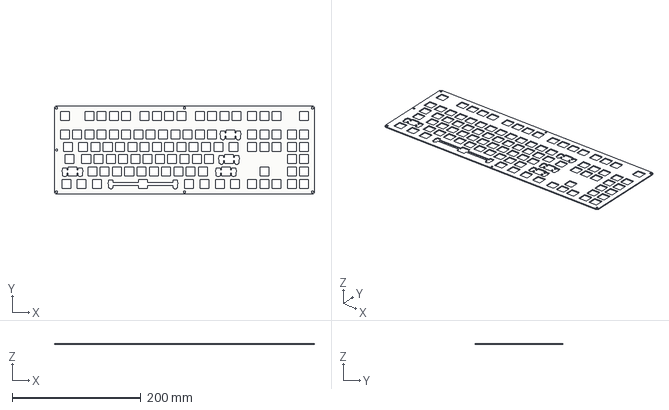
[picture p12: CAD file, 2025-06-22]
Models/plate.step
403.3 x 136.6 x 1.50 mm

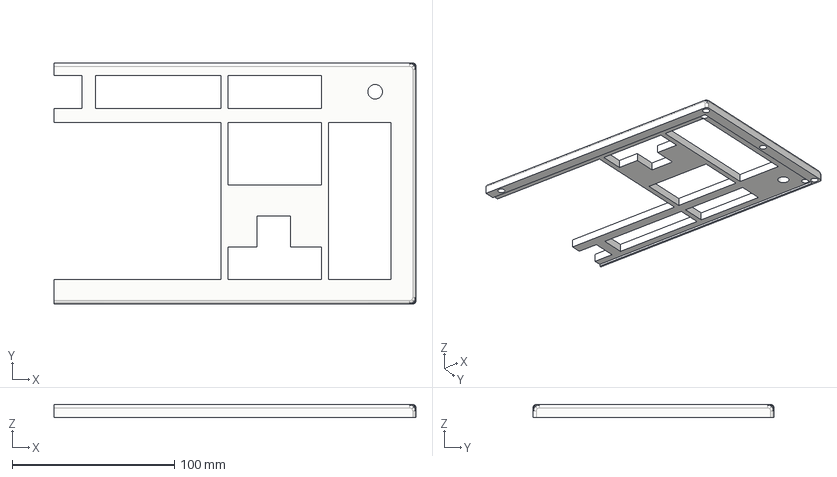
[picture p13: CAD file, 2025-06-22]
OVER-BUDGET/Production/CaseTopRight.step
222.9 x 148.4 x 8.00 mm

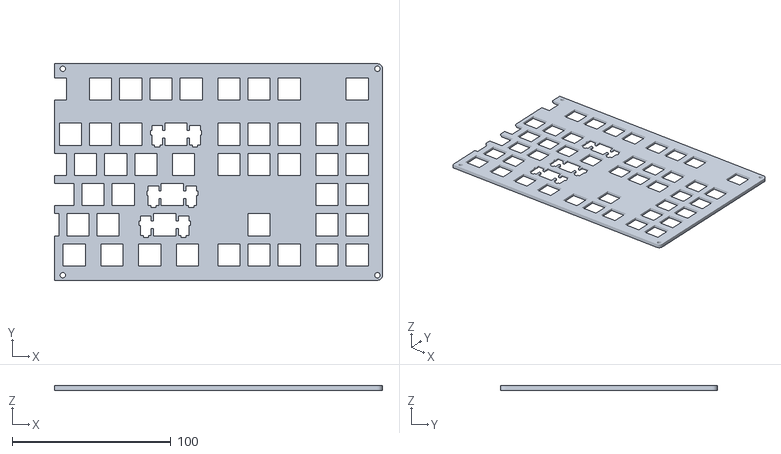
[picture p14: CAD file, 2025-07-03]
IN-BUDGET/Production/CAD/plateRight.stl
206.9 x 136.6 x 3.00

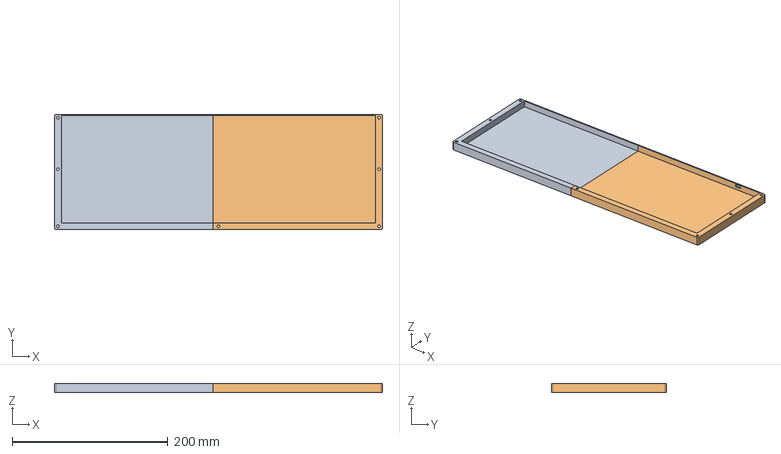
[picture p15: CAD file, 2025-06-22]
Models/CaseBottom.step
421.8 x 148.4 x 12.0 mm

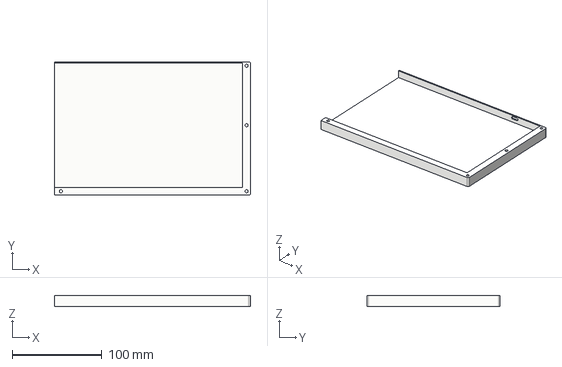
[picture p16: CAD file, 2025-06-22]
OVER-BUDGET/Production/CaseBottomRight.step
218.1 x 148.4 x 12.0 mm

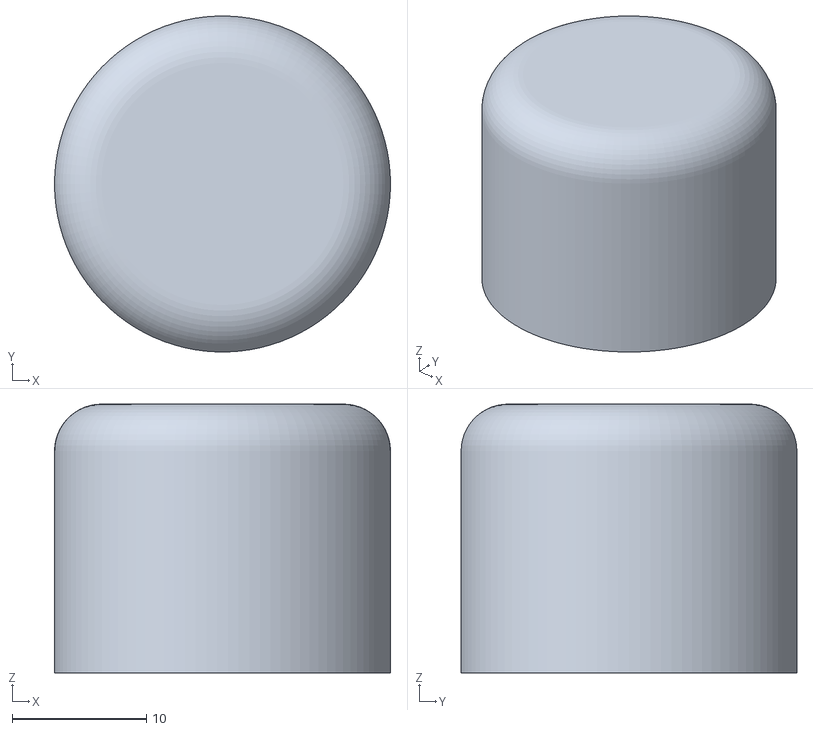
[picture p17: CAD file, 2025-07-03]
IN-BUDGET/Production/CAD/rotEncoderCap.stl
25.0 x 25.0 x 20.0

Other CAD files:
Models/CaseTop.step
IN-BUDGET/Production/CAD/CaseBottomLeft.stl
IN-BUDGET/Production/CAD/CaseBottomRight.stl
IN-BUDGET/Production/CAD/CaseTopLeft.stl
IN-BUDGET/Production/CAD/encoder_bracket_for_stab_hole.stl
OVER-BUDGET/Production/CaseTopLeft.step
OVER-BUDGET/Production/plate.step
OVER-BUDGET/Production/rotEncoderCap.step

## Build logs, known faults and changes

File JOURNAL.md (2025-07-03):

# Journal

# Information
- Title: "MacroBoard"
- Author: An. D. (its_kronos)
- Description: The MacroBoard is an extension of a much smaller "macropad" featuring a **full TKL layout** with a **rotary encoder** for volume and a whopping total of **22 macro keys** (10 macrokeys physically and 12 more due to the fn keys being on another layer).
- Creation Date: 6/8/2025
- Total Time (before building):39 hours 40 minutes 

# 6/8/2025
I started the general planning for the design criteria and also started sourcing some of the parts needed to create the keyboard. This took a lot longer than I expected, and I didn't realise how much actually had to go to making a full-sized keyboard, even after making a macropad before this.  

No images yet as it has mainly been a lot of researching and writing ideas, but here is what I have so far:  

* TKL layout (87 keys)
* One rotary Encoder with button (1 key, 2 additional GPIO)
* 10 macro buttons (10 keys)
* Total keys: 98
* Matrix size: 17x6
* total gpio for input keys (disregarding matrix): 10
* total gpio for input keys (regarding matrix): 23
* total gpio for input:25
* gpio for output: 2
* minimum gpio: 27  
  <br>
* USBC connectivity (JLCPCB part C2988369, costing 0.08)
* Cherry MX speed silver switches ([switches](https://www.aliexpress.us/item/3256802556025161.html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)) (for 47.67)
* white to light blue gradient keycaps ([keycaps](https://www.aliexpress.us/item/3256808583283524.html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)) (for 20.22)
* Diodes (JLC part C2099, costing 0.01 each), probable ordering via aliexpress (name: 1N4148W)  

Anyways, here are some goals that I have for the next session!!  
- Figure out a specific MCU to use and read the datasheets as well as sourcing all the parts required in this step
- Source some stabs
- Source a rotary encoder switch
- learn a bit more about a usb protection IC, should I get one, and if so, source it  

**Session length: 1 hour** (ish probably a couple minutes more excluding this journal entry)  

# 6/9/2025

Did a lot more research and sourced a LOT of components, and found out what remaining components i have to source before i can jump in (why is reading documentation so time consuming)  

* PCB mounted stabs [stabs](https://www.aliexpress.us/item/3256801500004993.html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) (for 5.26 total)
* EC11 rotary encoder switch [rot](https://www.aliexpress.us/item/3256806989461658.html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) (for 1.42)
* RP2040, costing 1.11 on JLC (part number: C2040)
* ESD protection costing 0.11 on JLC (part number:C7519)
* ordering diodes via jlc with pcba since i'm VERY new to soldering  
  <br>
* must source voltage converter from 5v to 3v3
* 100nF capacitors required for power pins, SHOULD be close to the power pins (one per power) (9 needed)
* 1 uF capacitors required for internal voltage pin, SHOULD be close to respective pins (two needed)
* remaining for this stuff added to the "to source" list below  
  <br>
* Flash memory: JLC part "C97521" for 0.77
* Crystal oscillator: JLC part "C20625731" for 0.38
* Voltage converter: JLC part "C26537" for 0.26  
  <br>
* Oh yeah I also just learned about basic vs extended parts and now am double checking to see if i can find basic for anything that I didn't already
* Using JLC part "C2128" for diodes instead of other one as previous listed  

TO SOURCE:
* 100nF
* 1 uF
* 1x2 pin header
* 1k ohm
* 15 pF
* 27.4 ohm
* 10uF  

GOALS
* source stuff
* start wiring and pcb making so i can actually give some pictures!!!  

**Session length: 1 hour 30 minutes**

# 6/11/2025

Started this session with sourcing the parts as my goal was from last session

* 100nF - C1525
* 1 uF - C1848
* 1x2 pin header - [headers](https://www.aliexpress.us/item/3256804251926023.html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) (for 1.44)
* 1k ohm - C85373
* 15 pF - C1548
* 27.4 ohm - C31439
* 10uF - C13585
* 5.1k - C23186

Yeah it became pretty easy for me to source parts after having done it for two days already, but at least i can now focus on the actual hardware!  
  
Finding information about the USB receptacle was pretty difficulty, and when I did it was pretty hard to digest, but I eventually figured it out (I needed a 5.1k ohm resistor pulled down to the cc pins)  
  
I was able to finish routing the usbc receptacle as well as the accompanying voltage convertor to the pi2040, but I still have to wire up the data and power lines to the pi before starting my key matrix  
  
routing progress:  



GOALS:  
  
* finish routing RPI
* Finish key grid

**Session length: 1 hour 15 minutes**

# 6/12/2025

Started off this session with finishing up the wiring for the pi completely, and I eventually realized that I needed a 10K ohm resistor to be able to reset the mcu into BOOTSEL should I need to reflash it.

* 10k ohm - C25744
* usb protection IC replaced to C7419953 because it has a recommended usb layout in datasheet
* Switching USBC connector to C165948 because it has a footprint that is easier to recreate

The wiring was pretty simple since this was the second time reading the rp2040 hardware documentation (first time to source parts), so I pretty much just followed that to result in the following:

  

Afterwards, I worked on my switch matrix, which honestly took more time than I thought it would. Understanding the logic behind a switch matrix compared to just directly wiring distinct switches to a controller took quite a while and gave me a few mistakes when I made my first draft, but eventually I ended up with: 

Matrix



After making the matrix, I decided that the keyboard would look better with the encoder on the right side of the macro keys, so I just switched it in the schematic sheet.  
  
At this point, my goal was to completely finish what I would have to do in the schematic side of things, so I could start the PCB, and the final step was to assign footprints.  
Assigning footprints to almost everything was a breeze, and locating which keys needed different sizings was pretty tedious, but when I tried to find a footprint for the USBC connection, I struggled.  

I spent a pretty long time researching to no avail, and eventually decided that my best option would be to just remake it in KiCad (which I decided to save for another time)

  (Note that the other time could be the same day, since these this process took 4.5 continuous hours)

GOALS:
- Custom footprint for usbc receptacle
- Double check the footprints for all components
- Start working on the PCB layout, start wiring if time permits

**session time 4:30**

Alright next session of the same day!

Made a footprint for the usbc receptacle!!! Took way too long to learn how to make my own footprint and match it exactly to the documentation (please add dimensioning kicad I'm begging you)



GOALS:
- Add and create the custom schematic diagram for the usbc receptacle
- double check footprints for all components

**session time: 1:30**

# 6/13/2025

- remade pi2040 shape to include all power pins for decoupling
I was pretty surprised that the base shape for the pi2040 didn't include all the power pins, as this is a pretty important detail since each power pin requires decoupling capacitors.
However, I easily fixed this by just making the pins visible in the editor.



- made usbc shape
This was overall pretty easy and didn't require much effort.



- labeling key names
I decided that labeling every key and diode would make placing parts exponentially faster (it did), but it was pretty tedious and time-consuming.



- triple checked all footprints and parts
Another big time dump was double checking all the footprints, but I did realize that some of my footprints for the cherry switches (like for the key for "\\") weren't the proper "U" sizing.

- started placing switches onto the pcb, but difficulty finding distance between the function keys
- used: https://keyboard-layout-editor.com/#/ to find distance in a standard layout
- finished placing every switch
- finished placing every diode
This by far was the most annoying part of the process, due to there being about 100 diodes to place. At least watching the switches line up so perfectly was pretty nice to watch.



GOALS:
- Place other components for PCB
- Start routing

**Session time 3:40**  

Session Two:
- Placed all of the other components 
- replacing 1uF with C52923 for smaller footprint



- Attemped to route but failed horribly with the differential pair

GOALS:
- Change up the part layout
- replace data line protection part so I don't have to use vias

**Session Length: 1:30** (most of the time was spent on trying to make sure there's enough space, but I severely underestimated the size traces are)

# 6/14/2025

- Created a running list of all the parts used so far
* placed all of the parts again in a more organized way
* Tried to do differential pair routing but got confused with the wiring of the ESD protection, wondering if the impedence should be split among both sides.
* After quite a bit of research I realized that they are internally connected and was able to successfully route it
* Had some power symbols with 3v3 and 3.3 which made the nets slightly wrong
* wired all the rows and columns (but not to the chip)
* wired most (if not all) of the stuff for the chip





GOALS:
- double check the list for all running parts
- finish the routing and pcb

**time: 3 hours**

# 6/16/2025

* routed most of the rows and colums as well as rearranging the crystal so it can have a ground plane
* This was overall pretty easy, but sometimes the routing was a bit difficult, and I had to rearrange things so that the traces could fit properly
* I also sometimes had to think for a bit of a way to connect two tracks without boxing myself in for the other rows and columns.





* learned about length matching for the USB port and did a bit of research about it as well as implementing it



GOALS:
- Finish the routing of the PCB
- Double check the list for all running parts

**TIME: 1 hour 15 minutes**

Next session:

- Completed the entire routing and ground planes for the PCB, and it looks pretty good in my opinion



GOALS:
- Find and add 3d models for some of the footprints (key switches, ec11, stabs, usbc connector, etc.)
- Double check running list of parts (i'm too lazy to go back and read every journal entry again, but i'll have to do it before adding 3d models 😭 so I don't position the wrong one)

**TIME: 1 hour 45 minutes**

# 6/17/2025

* checked running list and footprints
* added 3d components
* wondered if the metal piece between stabs needed holes in the plate, so I researched about that using previous submissions for highway, but this wasn't enough so I researched more
* Found a youtube video showcases the removal of stabs from a plate, and found that it was mainly just for allowing easy of removal from plate-mount stabs, but since i'm using plate mount, it would be better to include them
* decided to include hotswap sockets from kailh in the build, and sourcing them here (they are the cheapest among amazon and aliexpress): [amazon hotswap](https://www.amazon.com/DUROCK-Mechanical-Keyboard-Switches-Hot-Swap/dp/B0B4W9YMGM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)
* added footprints for hotswap
* sadly have to reroute pretty much every single row and column due to having slightly different plated through hole sizing (and underside pad/component placement)!



**TIME: 2 hours**

*session 2*

* even after removing all row and column tracks, all the pins for the switches are reversed, so I also have to redo all the diodes, which means that it would most likely be faster to reroute the entire board rather than taking the time to find each individual track connected to a diode and remove it, as well as reposition the diode



* was able to route all the columns to eachother (not the pi)
* moved each diode and connected it to each keyswitch
* routed up all the stuff near the pi except for the crystal (routing heavily depends on how tightly i can route the columns and rows)



**time: 1h15m**

# 6/18/2025

* finished rerouting the entire board
* added courtyard to the usbc connector
* added some stuff to the silkscreen





* generated the plate with a keyboard layout, and it'd be too big for most household 3d printers, so I'm asking if I'd be allowed to use JLC3DP



* had to scale down the plate since it was 10x bigger in fusion



**time: 3.5 hours**

*session 2*

* after checking the parts, replacing old stabs with [stabs](https://www.aliexpress.us/item/3256806342416791.html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) because the old ones had pictures that didn't look like plate mount, but in the product here it clearly says plate mounted
* Did some research on whether the pcb would need to be supported or not, but I decided it would be for the best if they were and found standoffs i could use [standoffs](https://www.aliexpress.us/item/3256807945933515.html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)
* resized edge.cuts and adding mounting holes, and this part took way too long because theres no tool for distancing like there is in many cad programs, so I had to align everything perfect with the grids, which was pretty annoying (also had to reroute and reposition the USBC receptacle due to board resizing)



* Setup wakatime for kicad and fusion

**time 1h45m**

# 6/19/2025

* i'm pretty new to cad so making the case will take quite a bit
* finished the bottom part of the case with holes for screws



* added bigger holes at the bottom for the head, with the following sourced M3 screws: [screws](https://www.aliexpress.us/item/3256808318392916.html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)



* will be adding the hole for the usbc connector last, so i can align everything in the assembly and put the cutout accurately

**time: 45m**

* finished top part of the case, except for the spaces between escape and other keys, arrow keys, etc.
* I'll add that part after finishing up with the assembly



* full assembly before keycaps, stabilizers, colouring, and polishing



* couldn't find a stabilizer model i could use, so i'm going without it
* added all keycaps, but this took way too long since i was initially moving and copying them one by one before I learned I could use rectangular patterns



* polished up the top part of the case so that the gaps are filled



**time 3h15m**

# 6/20/2025

* redoing all the keycaps because it is the only way for me to unlink all of them so i can apply the custom colors
* found different keycaps for all the u sizes after some searching
* the new models for the keycaps were all scaled up and meshes, so i decided to find other ones since i couldn't convert them prismatically (fusion free version sob)



* after doing some more digging i found different keycap models (we love reddit) which had everything for each row with the [link](https://github.com/ConstantinoSchillebeeckx/cherry-mx-keycaps) and this included keycaps for different rows, so I decided to restart again for the next session

**time:1h45m** (mainly because I spent so much time restarting and searching)

* turns out all the files i found before were just mesh-based too, which wasn't really helpful
* learned that all STL files are meshed based, so I will download the STEP file from the github repo instead
* Used the step file instead and it worked so much better, and i was able to get a lot of keys placed down, and the keyboard is starting to look really good



**time: 45m**

# 6/21/2025

* finished putting all the keys and colouring, and imported my rotary encoder cap from another project (hackpad), but didn't know which ec11 rotary encoder type comes with hackpad, due to there being so many different variations, so I asked which specific type it is and tried to do some research
* the type is the ec11e 
* since the 3d model on the pcb in the assembly is not an ec11e (and since I couldn't find an ec11e model, just one for a general ec11 encoder) i had to carefully go by the measurements on the datasheet to design my cap
* spent quite a long time designing the hole for the USBC connector, making it pretty tight with some clearance just incase





**time: 1h30m** (excluding some time about asking details to improve my case)

* sourced some gorilla superglue gel I would use for the standoffs in the plastic after doing some research about which glue works well with PLA
* started splitting all the prints so they could be printed with printing legion



* decided not to split the plate because splitting it would make it pretty difficult to print secure during shipping, so i'll probably use JLC3DP for this one part
* discovered that JLC3DP PLA print has to have a minimum of 1cm height and their capabilities don't support 1.5mm height, but after some research I discovered that many people use FR4 as material for their plates, so I did a big brain move and exported the plate sketch as a DXF and imported it into kicad and just exported as gerber!



* turns out that JLCPCB is pretty expensive for getting plates, so instead I decided to just get it via a resin print, which can support 1.5mm thick prints
* replacing 1k ohm with C11702, since it's a basic part
* turns out that no matter what I do the weight will be over 1.5 KG for the board alone, so I have to pay about 40 dollars shipping to the US, which means that the rest of the board is unfeasable to design
* i will finish a draft of the code and create a BOM, but that's about it since I don't have the means to pay the exorbitant amount of money required

**time: 30m**

| Ok thanks to some ideas of @TheEternalComrade (fellow Hackclub member), I decided that after finishing a draft of the code and a BOM for this expensive version of the keyboard, I will use the grant to aquire the materials needed to handsolder the keyboard instead of paying 100 dollars for a PCB including shipping

# 6/22/2025
* created a bom for the over-budget build
* created a draft of code to use on the keyboard



* sourced parts that would be needed for hand-wired keyboard
* edited case to support a USBC breakout board instead of the over-priced PCB (lowered the hole)
* editing plate to support thicker printing and better support so I can use printing legion instead
* editing the plate is taking way too long due to fusion taking like 30 seconds to render a single constraint and up to two minutes if I misclick



**time: 2 hours**

* found a cherry MX plate hole to EC11 rotary encoder by @Coloneljesus_13723 on printables.com, which would allow me to glue a rotary encoder to it and attach it securely to the plate without a PCB (pretty fire)
* finished redesigning the plate to be thicker to allow for more security and smaller bed size required for printing (I wish fusion ran faster)



* made bom and added it to readme
* Created a readme and added almost everything that I need to

**time: 2h30m**

# 7/3/2025

- Just remade the case a bit (nothing major, small number changes) to be more suitable for 3d printing

**TIME: 30m**

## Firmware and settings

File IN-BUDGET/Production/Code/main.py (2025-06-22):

import board

from kmk.kmk_keyboard import KMKKeyboard
from kmk.keys import KC
from kmk.scanners import DiodeOrientation
from kmk.modules.encoder import EncoderHandler
from kmk.extensions.media_keys import MediaKeys
from kmk.modules.layers import Layers




encoder_handler = EncoderHandler()

keyboard = KMKKeyboard()

keyboard.modules.append(encoder_handler)
keyboard.modules.append(MediaKeys())
keyboard.modules.append(Layers())

encoder_handler.pins = (
    (board.GP1,board.GP0,None)
)
encoder_handler.map(
    ((KC.VOLD,KC.VOLU,None))
)


layer = KC.MO(1)

keyboard.col_pins = (board.GP10,board.GP11,board.GP12,board.GP13,
                     board.GP16,board.GP17,board.GP18,board.GP19,board.GP20,board.GP21,
                     board.GP23,board.GP24,board.GP25,board.GP26,board.GP27,board.GP28,board.GP29,board.GP9,board.GP2)
keyboard.row_pins = (board.GP3,board.GP8,board.GP7,board.GP6,board.GP5,board.GP4)
keyboard.diode_orientation = DiodeOrientation.COL2ROW

keyboard.keymap = [
    [KC.ESC,None,None,None,None,None,None,None,None,None,None,None,None,KC.PSCR,KC.SLCK,KC.PAUSE,KC.MUTE,
     KC.GRAVE,KC.N1,KC.N2,KC.N3,KC.N4,KC.N5,KC.N6,KC.N7,KC.N8,KC.N9,KC.N0,KC.MINS,KC.EQUAL,KC.BSPACE,KC.INS,KC.HOME,KC.KC.PGUP,KC.F13,KC.F14,
     KC.TAB,KC.Q,KC.W,KC.E,KC.R,KC.T,KC.Y,KC.U,KC.I,KC.O,KC.P,KC.LBRACKET,KC.RBRACKET,KC.BSLASH,KC.DEL,KC.END,KC.PGDN,KC.F15,KC.F16,
     KC.CAPS,KC.A,KC.S,KC.D,KC.F,KC.G,KC.H,KC.J,KC.K,KC.L,KC.SCOLON,KC.QUOTE,KC.ENTER,KC.F17,KC.F18,
     KC.LSHIFT,KC.Z,KC.X,KC.C,KC.V,KC.B,KC.N,KC.M,KC.COMMA,KC.DOT,KC.SLASH,KC.RSHIFT,KC.UP,KC.F19,KC.F20,
     KC.LCTRL,KC.LWIN,KC.LALT,KC.SPACE,KC.RALT,KC.RWIN,layer,KC.RCTRL,KC.LEFT,KC.DOWN,KC.RIGHT,KC.F21,KC.F22],
    

    [KC.ESC,KC.F1,KC.F2,KC.F3,KC.F4,KC.F5,KC.F6,KC.F7,KC.F8,KC.F9,KC.F10,KC.F11,KC.F12,KC.PSCR,KC.SLCK,KC.PAUSE,KC.MUTE,
     KC.GRAVE,KC.N1,KC.N2,KC.N3,KC.N4,KC.N5,KC.N6,KC.N7,KC.N8,KC.N9,KC.N0,KC.MINS,KC.EQUAL,KC.BSPACE,KC.INS,KC.HOME,KC.KC.PGUP,KC.F13,KC.F14,
     KC.TAB,KC.Q,KC.W,KC.E,KC.R,KC.T,KC.Y,KC.U,KC.I,KC.O,KC.P,KC.LBRACKET,KC.RBRACKET,KC.BSLASH,KC.DEL,KC.END,KC.PGDN,KC.F15,KC.F16,
     KC.CAPS,KC.A,KC.S,KC.D,KC.F,KC.G,KC.H,KC.J,KC.K,KC.L,KC.SCOLON,KC.QUOTE,KC.ENTER,KC.F17,KC.F18,
     KC.LSHIFT,KC.Z,KC.X,KC.C,KC.V,KC.B,KC.N,KC.M,KC.COMMA,KC.DOT,KC.SLASH,KC.RSHIFT,KC.UP,KC.F19,KC.F20,
     KC.LCTRL,KC.LWIN,KC.LALT,KC.SPACE,KC.RALT,KC.RWIN,KC.TRNS,KC.RCTRL,KC.LEFT,KC.DOWN,KC.RIGHT,KC.F21,KC.F22]
]

if __name__ == "__main__":
    keyboard.go()

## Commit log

2025-06-22 Update README.md - Bom added to readme
2025-06-22 add files to git repo
    [BOM.csv, CaseBottom.step, CaseBottomLeft.step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]
2025-06-22 reformat order
    [BOM.csv]
2025-06-24 changed rot encoder cap for better dimensions
    [rotEncoderCap.step]
2025-06-25 changed production step files to STL
    [CaseBottomLeft.step, CaseBottomLeft.stl, CaseBottomRight.step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]
2025-06-29 added more clearence to models
    [CaseTopLeft.stl, CaseTopRight.stl, rotEncoderCap.stl]
2025-07-03 made the case better in terms of 3d printing
    [CaseTopLeft.stl, CaseTopRight.stl, plateLeft.stl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]
